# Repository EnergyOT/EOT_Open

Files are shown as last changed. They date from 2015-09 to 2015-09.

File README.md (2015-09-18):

### EOT Open

**Docs:** Documents with information

**Hardware:** PDF's of eagle schematic, board and BOM files for building your own EnergyOT

**Firmware:** An open firmware to be used with open platforms (thingspeak) that you can flash into your energyot meter instead of using the platform my.eot.pt. Beware that you if reprogram your device you will lose forever access to the platform my.eot.pt.

**Tools:** A set of helper tools for flashing and programming your EnergyOT.

**Website:** www.eot.pt

**Mail:** contact@energyot.pt

<br />This work is licensed under a <a rel="license" href="http://creativecommons.org/licenses/by-nc-sa/4.0/">Creative Commons Attribution-NonCommercial-ShareAlike 4.0 International License</a>.

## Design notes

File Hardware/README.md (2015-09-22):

## EOT Open Hardware

#### BOM

- **energyot_open_BOM.xlsx** - Bill of Materials

#### Schematic

- **energyot_open_schematic.pdf** - Schematic

#### Layout

- **energyot_open_top_layout.pdf** - PCB TOP
- **energyot_open_bottom_layout.pdf** - PCB BOTTOM
- **energyot_open_all_layout.pdf** - PCB COMPLETE

#### Programming Details

- **programming pads.png**
- **programming usb.png**

##TO PROGRAM

You will need an USB to serial converter (like FTDI or Prolific). Then there are two ways that you can program this hardware:

 - You can use the programming pads in the bottom side with pogopins or a custom made cable (check programming pads.png). 
 - You can close the solder jumpers in the bottom (J1, J2 and J3) and use the uUSB cable to program. Notice that after programming you should open the solder jumpers again check programming usb.png).
 
Notice that the usb to serial converter should be 3.3V and during the programming phase you will need to pull the GPIO0 pin to ground.

**Website:** www.eot.pt

**Mail:** contact@energyot.pt

<br />This work is licensed under a <a rel="license" href="http://creativecommons.org/licenses/by-nc-sa/4.0/">Creative Commons Attribution-NonCommercial-ShareAlike 4.0 International License</a>.

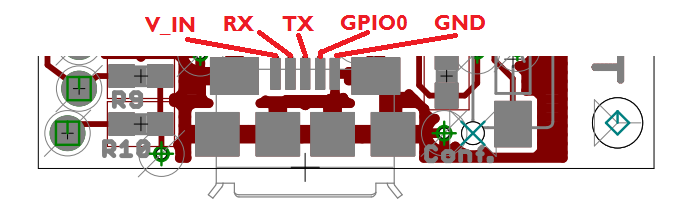
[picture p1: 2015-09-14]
Hardware/programming usb.PNG

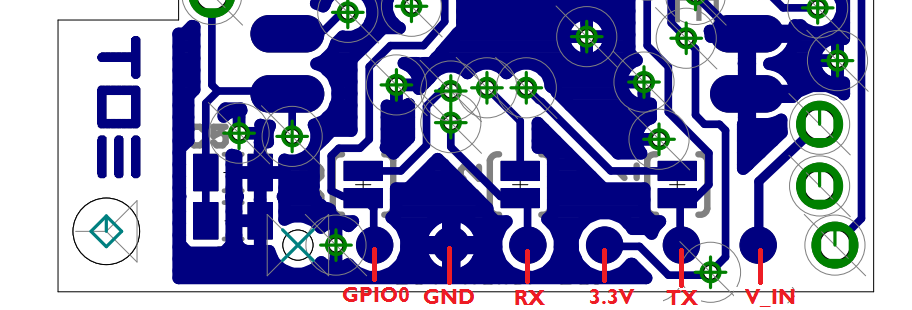
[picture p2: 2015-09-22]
Hardware/programming pads.PNG

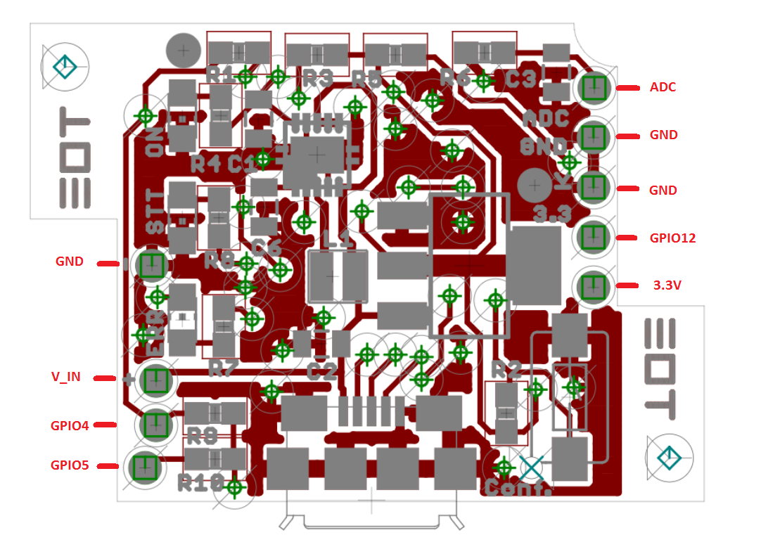
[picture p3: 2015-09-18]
Hardware/pinout.png

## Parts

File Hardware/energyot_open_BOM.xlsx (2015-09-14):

EnergyOT_OPEN V1.0 BOM
Part | Value | Device | Package (mils)
C1 | 22u, 16V | CAP0805 | 805
C2 | 10u, 16V | CAP0805 | 805
C3 | 1u, 16V | CAP0805 | 805
C4 | 10u, 16V | CAP0805 | 805
C5 | 0.1u, 16V | CAP0805 | 805
C6 | 1u, 16V | CAP0805 | 805
CONFIG. | SWITCH-MOMENTARY-2-SMD-1101NE | SWITCH-MOMENTARY-2-SMD-1101NE | TACTILE-SWITCH-1101NE
ESP12 | ESP12 | ESP12 | ESP12
L1 | 2.2uH | EPL2014-222MLC | EPL2014
ERR | RED | LEDCHIP-LED0805 | CHIP-LED0805
STT | BLUE | LEDCHIP-LED0805 | CHIP-LED0805
POW | GREEN | LEDCHIP-LED0805 | CHIP-LED0805
R1 | 4.7k | RESISTOR0603-RES | 0603-RES
R2 | 10k | RESISTOR0603-RES | 0603-RES
R3 | 10k | RESISTOR0603-RES | 0603-RES
R4 | 4.7k | RESISTOR0603-RES | 0603-RES
R5 | 10k | RESISTOR0603-RES | 0603-RES
R6 | 13k | RESISTOR0603-RES | 0603-RES
R7 | 4.7k | RESISTOR0603-RES | 0603-RES
R8 | 4.7k | RESISTOR0603-RES | 0603-RES
R9 | 4.7k | RESISTOR0603-RES | 0603-RES
R10 | 4.7k | RESISTOR0603-RES | 0603-RES
U_USB | 10118192-0001LF | 10118192-0001LF | 10118192-0001LF
IC1 | AP2114H-3.3TRG1 | AP2114H-3.3TRG1 | SOT-223
IC2 | TPS61201 | TPS61201 | S-PDSO-N10

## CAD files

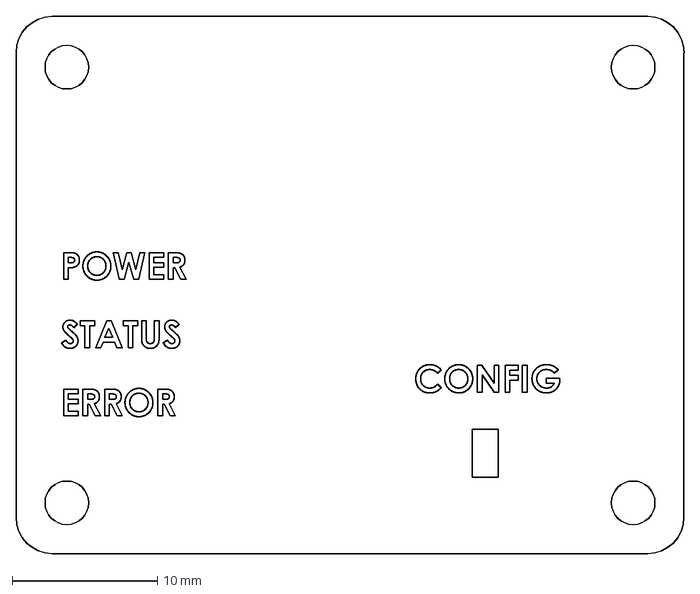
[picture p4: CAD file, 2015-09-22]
Enclosure/topo.DXF
46.0 x 37.0 mm

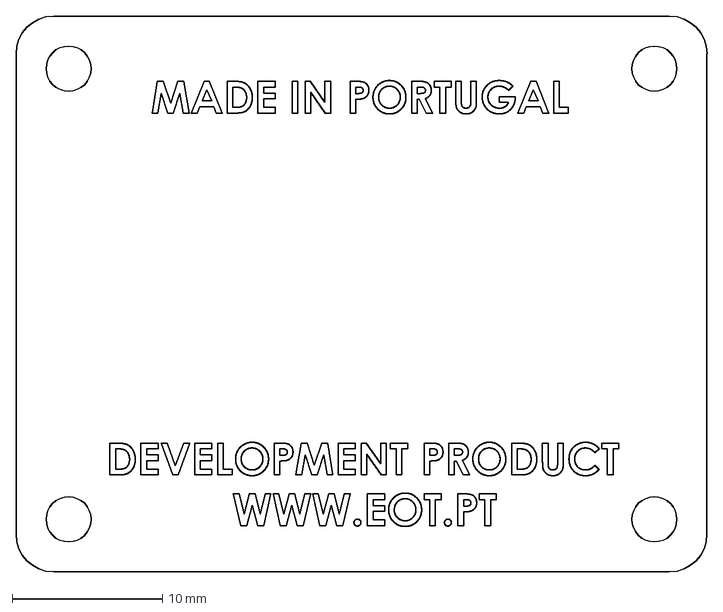
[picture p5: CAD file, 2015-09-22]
Enclosure/bottom.DXF
46.0 x 37.0 mm

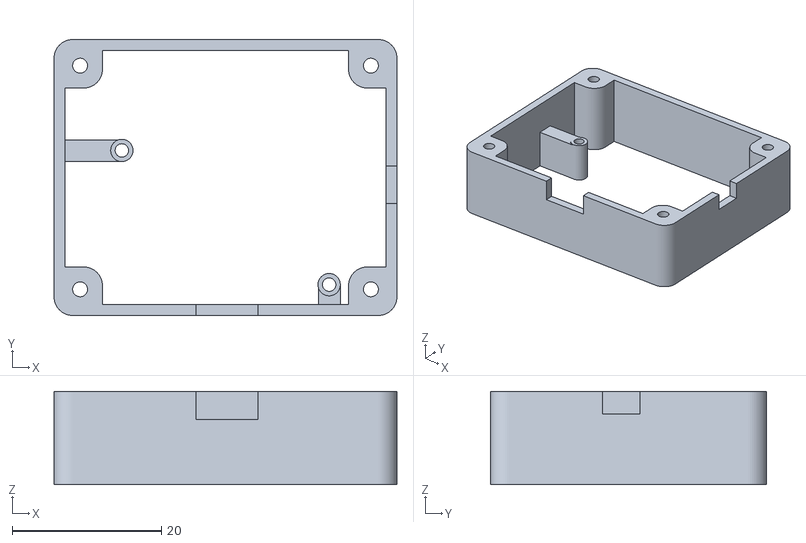
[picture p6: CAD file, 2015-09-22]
Enclosure/Middle 3D Print.STL
46.0 x 37.0 x 12.5

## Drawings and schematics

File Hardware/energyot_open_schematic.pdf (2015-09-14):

# 3.3V ERROR

A

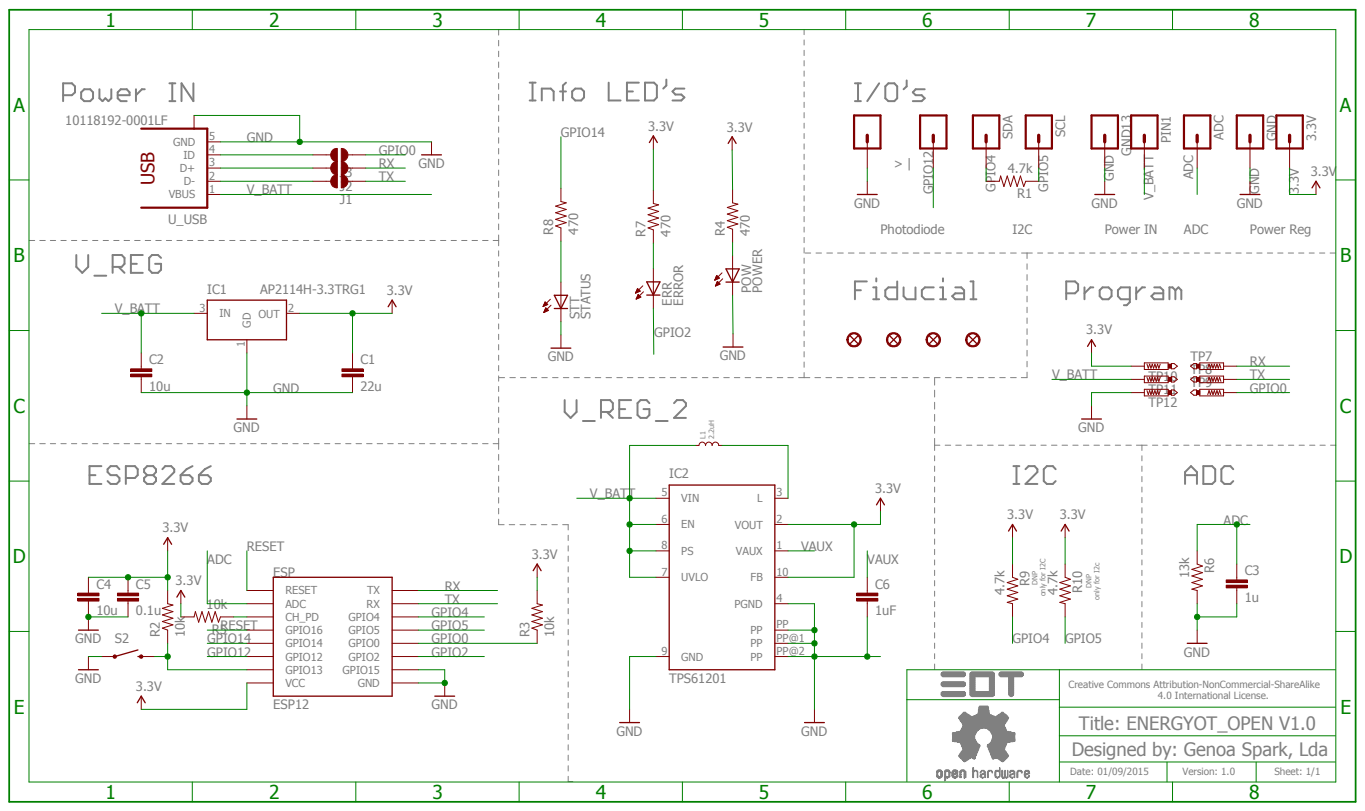
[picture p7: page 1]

Creative Commons Attribution-NonCommercial-ShareAlike

Title: ENERGYOT_OPEN V1.0
Designed by: Genoa Spark, Lda

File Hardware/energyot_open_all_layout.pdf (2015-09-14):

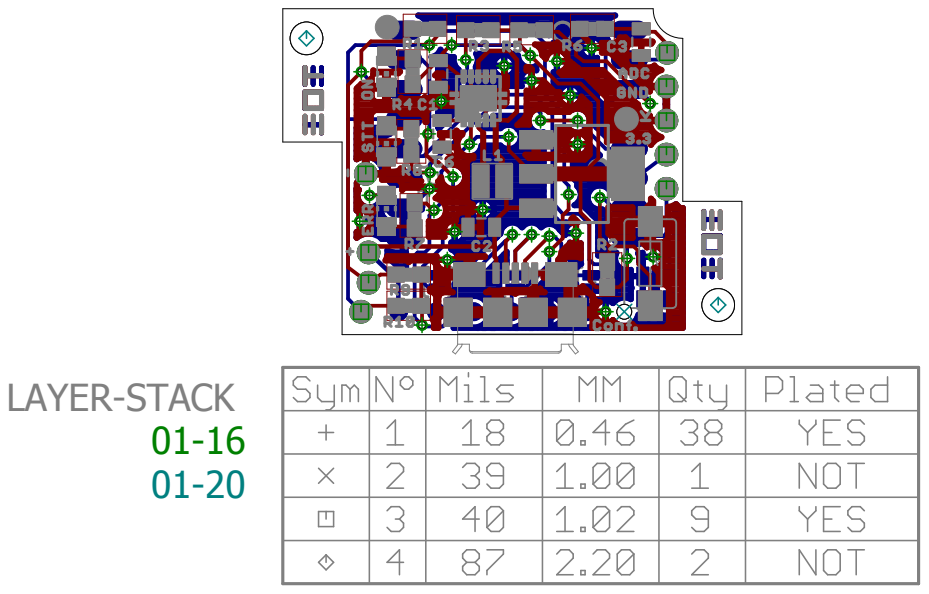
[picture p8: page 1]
ESP - 12; LAYER-STACK 01-16 01-20

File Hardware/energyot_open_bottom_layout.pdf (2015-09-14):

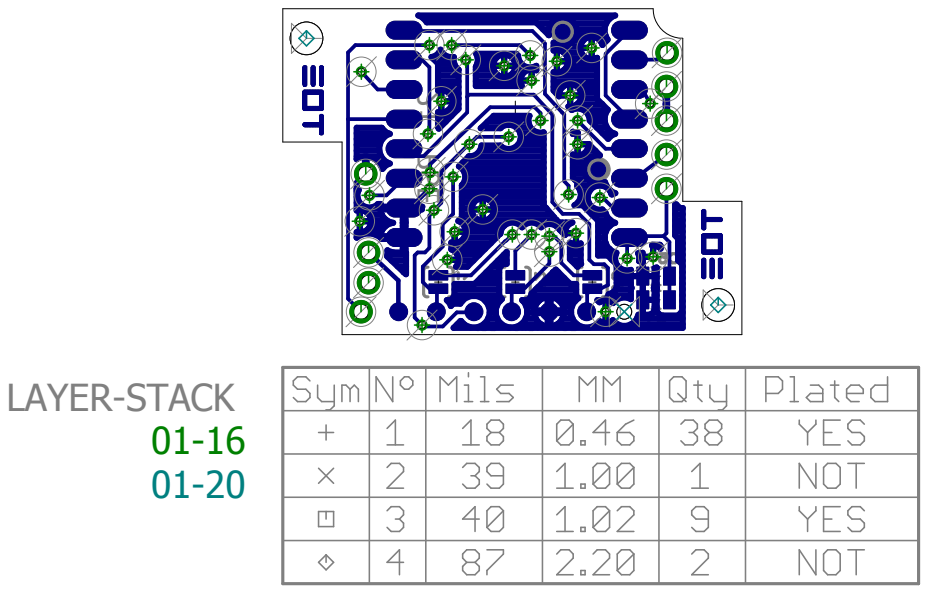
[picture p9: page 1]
ESP - 12; LAYER-STACK 01-16 01-20

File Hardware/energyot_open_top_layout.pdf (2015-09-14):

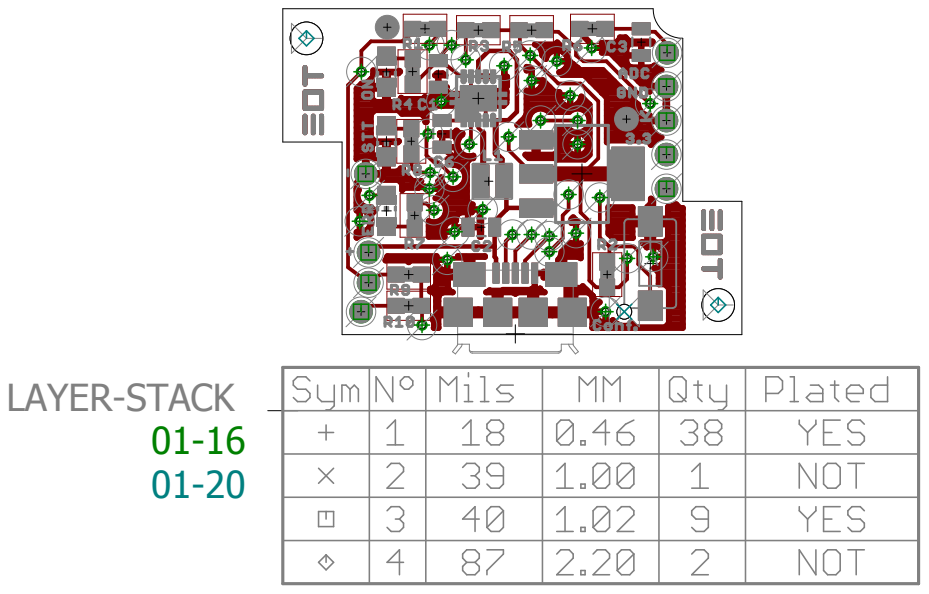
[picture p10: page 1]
LAYER-STACK 01-16 01-20

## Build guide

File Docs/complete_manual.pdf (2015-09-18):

## Version: Optic

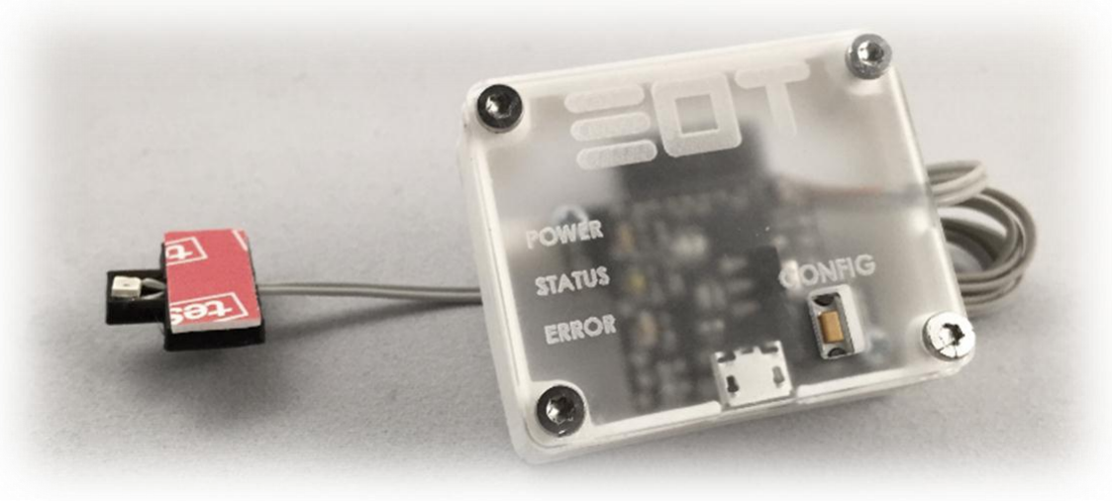
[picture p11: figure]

# COMPLETE MANUAL

September 2015 (English), version 1.0. EnergyOT Optic Developed and Manufactured by Genoa Spark, lda Made in Portugal

Specifications are subject to change without notice.
All product names are trademarks of their respective companies. http://www.eot.pt

# TABLE OF CONTENTS

# INTRODUCTION

The EnergyOT Optic version is a development device that measures the energy consumption of your home or business using an optical sensor that is glued to your energy meter, on top of the LED that indicates the Pulses/kWh. Once installed and configured this device reads, processes and sends the power consumption directly to your account in the cloud.

The EnergyOT uses the my.eot.pt platform to collect data and give you direct and real-time access to your energy consumption. To save on energy costs and contribute to a greener environment, you can use this information to take on energy guzzlers and standby power.

This manual describes the installation of the EnergyOT Optic version, as well as means of operation, configuration and troubleshoot.

# READ BEFORE USE

## MANUFACTURER'S DISCLAIMER STATEMENT

The information in this document is subject to change without notice and does not represent a commitment on the part of the vendor. No warranty or representation, either expressed or implied, is made with respect to the quality, accuracy or fitness for any particular purpose of this document. The manufacturer reserves the right to make changes to the content of this document and/or the products associated with it at any time without obligation to notify any person or organization of such changes. In no event will the manufacturer be liable for direct, indirect, special, incidental or consequential damages arising out of the use or inability to use this product or documentation, even if advised of the possibility of such damages.

This document contains materials protected by copyright. All rights are reserved. No part of this manual may be reproduced or transmitted in any form, by any means or for any purpose without expressed written consent of its authors. Product names appearing in this document are mentioned for identification purchases only. All trademarks, product names or brand names appearing in this document are registered property of their respective owners.

## WARNINGS

- Please observe the following safety precautions to avoid possible electric shocks, fire, or personal injury:
- Use the product only as specified as otherwise the safety of the product is not sufficient.
- Do not use the product in environments with explosive gas or vapors, nor in damp or wet environments.
- Do not use damaged power cords and cables. Check the power cords and cables for damaged insulation and exposed metal. Check the connection of the power cord.
- Do not use the product if it is damaged.
- Reparations should only be done by authorized technicians.
- Do not open the product. There is a potential for damaging the equipment.
- Do not cover the device with metallic materials or metallic tape. It will seriously reduce the Wi-Fi signal.

## MAINTENANCE

- Clean only the outside with a dry, clean cloth.
- Do not use abrasive agents, abrasive glues or solvents.
- Glue the device to the energy meter only with nonconductive tapes.
- Check the troubleshoot section or contact the support team before trying to manually fix a nonfunctioning device.

## TECHNICAL SPECIFICATIONS

- Dimensions: 37 mm (L) x 46 mm (W) x 18.5 mm (H)
- Wi-Fi 802.11 b/g/n 2.4 GHz
- Work temperature: -25°C to 50°C
- Storage temperature:-10°C to 60°C
- Relative humidity: 80%, 0°C to 40°C
- Work altitude: 0 to 2.000 meters
- Weight: 20g
- Enclosure Material: PLA

## WHAT'S IN THE BOX

Congratulations on being the owner of the EnergyOT Optic! Your box should include:

- EnergyOT Optic;
- Sensor with installation accessory.
- Documentation for installation and configuration.

# INSTALLATION INSTRUCTIONS

## DESCRIPTION

This section was developed to help you physically install the EnergyOT Optic in your energy meter. There is no need for an electrician since you won’t be touching any electric wires, just the energy meter itself. Follow the next set of quick instructions and you should be set.

## INSTALLATION

1. Using tape, center and attach the sensor on the Energy Meter led that indicates the Impulses by kWh. Check examples of the led location below;

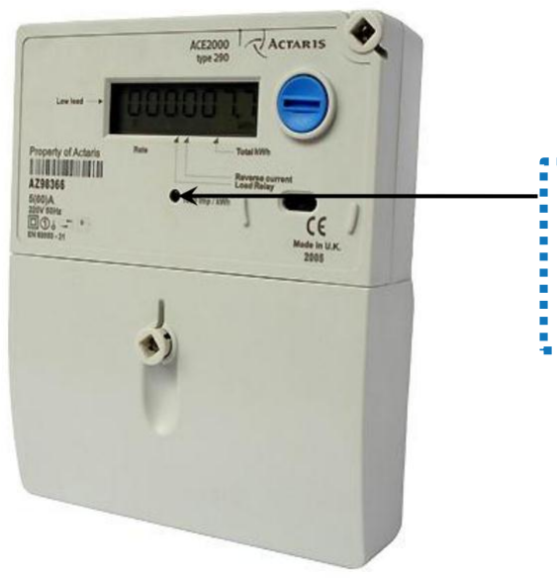
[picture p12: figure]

Location of the Imp/kWh
led where the sensor
should be placed.

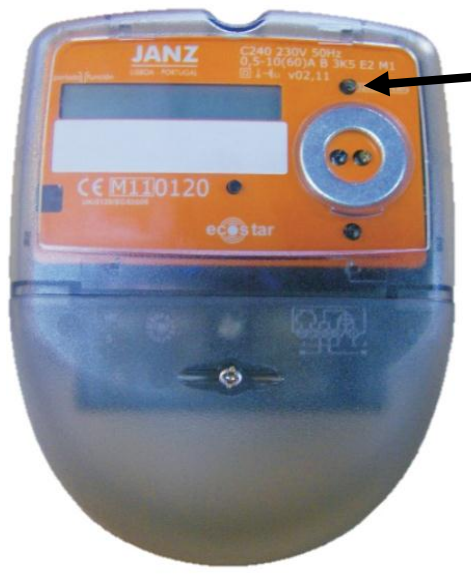
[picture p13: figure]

Location of the Imp/kWh
led where the sensor
should be placed.

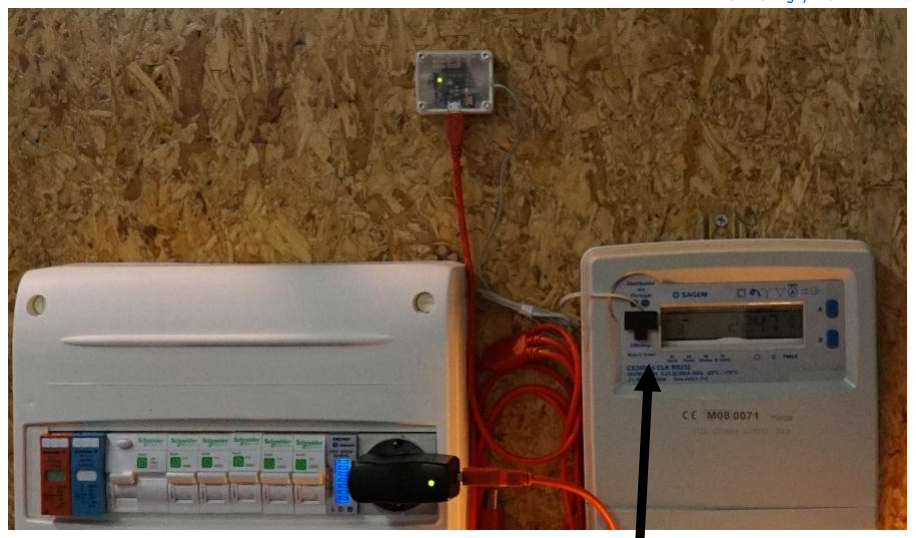
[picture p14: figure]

2. Place the EnergyOT monitor anywhere suitable for you but try to face it outside in order to access the configuration button, see the leds and maximize the wireless reach;
3. Connect the mini USB power cable supplied to the EnergyOT monitor and the green Led should light up indicating that is powered;
4. Also the blue led should be on and the red led should be blinking indicating that the device is new and not yet configured to a wireless network. To configure it check the operation section of this manual;
5. If you are experiencing any problems with the installation check the troubleshoot section of this manual or contact the support team.

If you are finding it difficult to glue the EnergyOT to your Energy Meter you may add more double sided tape or other type of tape to secure the sensor to your Energy Meter.

Sensor applied in the energy Meter

# OPERATION INSTRUCTIONS

## DESCRIPTION

This guide was developed to help you configure your EnergyOT Optic. This guide assumes that you already have the EnergyOT Optic installed in place. If so follow the next set of quick instructions otherwise check the installation section in this manual first.

## FRONT PANEL

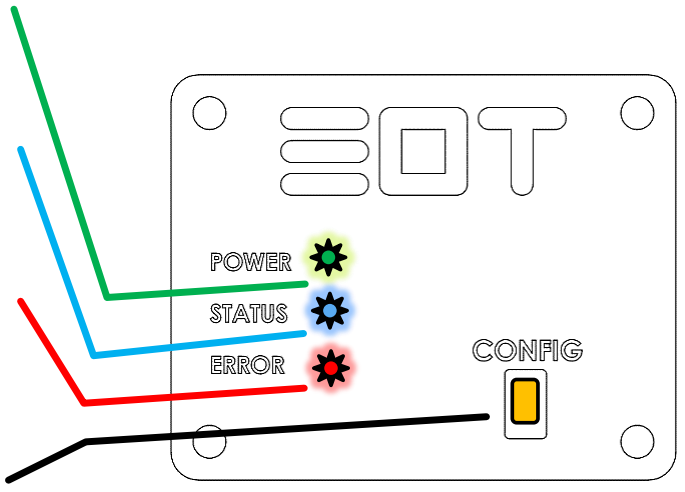
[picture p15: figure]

## CONFIGURING YOUR DEVICE TO YOUR

## NETWORK

1. You must register in the my.eot.pt platform before starting the device configuration.
2. Plug the micro USB to the EnergyOT device in order to power it.
3. You have 5 seconds from the moment you power the EnergyOT to press the configuration button.
4. All LEDs will light up (green, blue and red) indicating that the device is now in configuration mode (If by any chance you have not been able to press the Config. button within the 5 second limit switch it off, turn it on and try again) .
5. Download the configuration tool that best suit the platform that will use (Windows, Mac, Linux or Android) in www.eot.pt/en/downloads.html
6. Follow the instructions of the configuration tools. Briefly these applications will point you to:

Power Led – Indicates if the device is powered.

Status Led – Blinks accordingly with the energy consumption.

Error Led – Indicates the existence of errors.

Configuration Button – To configure your EnergyOT.

a. Login in the application with the email and password of your account in the my.eot.pt platform and choose to activate a new EnergyOT;

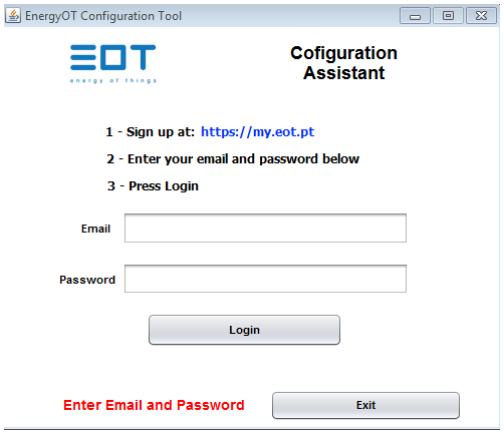
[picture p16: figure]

b. Enter the SSID and password of your wireless network.

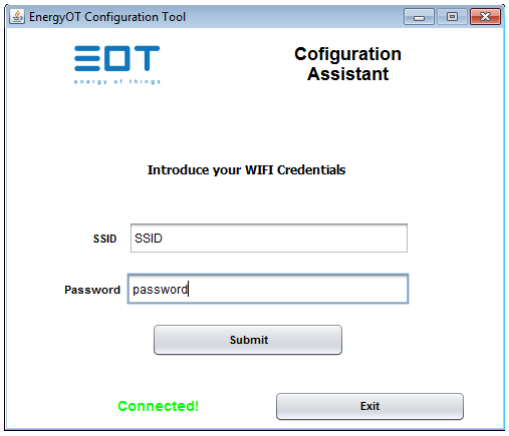
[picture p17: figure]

c. After you have entered all the parameters change your wireless network and connect to the network generated by the EnergyOT (the SSID of the network is EnergyOT xx-xx-xx-xx).
d. Make sure that at this stage your computer is connected to the EnergyOT (EnergyOT xx-xx-xx-xx), and click "Configure EnergyOT".

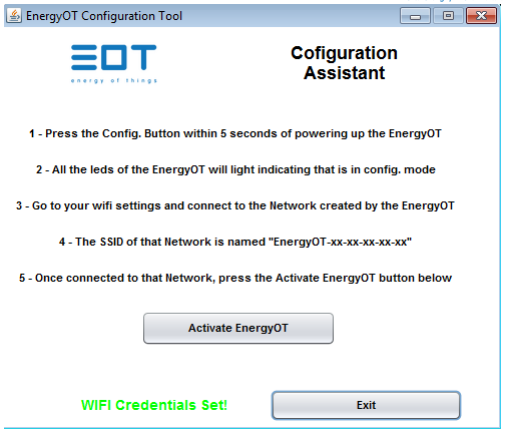
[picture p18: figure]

7. The EnergyOT Monitor is now configured! Congratulations! Now you can check your data online.
8. If you are experiencing any problems with the configuration check the troubleshoot section in this manual or contact the support team.

If you want to change or made a mistake entering your network SSID or Password, you need to go back to step 1 again.

# TROUBLESHOOT

## DESCRIPTION

When operating the EnergyOT Óptic device you may run into issues. This is a handy guide to some simple-to-fix problems. Also, if your device has been stolen, contact us so that we can disable the equipment.

## SUPPORT

If you have any questions regarding the EnergyOT Optic that are not contemplated in this troubleshoot section please send an email to our support team: contact@energyot.pt.

Problem | Solution
The device doesn’t turn on (green led doesn’t light up). | • Try to replace the micro USB power supply unit. • Have any components been damaged? Visually inspect both sides of the device. • Try to press the configuration button shortly after powering it up to see if the other two led’s light up (If so, the device works but the green led is broken).
The device does not send data - The blue led is on and the red led is blinking. | • The EnergyOT Optic is not configured to your Network, follow the instruction in the Operations section to configure it.
The device does not send data – The blue and red led’s are blinking synchronously. | • The device failed to connect with the platform, try to re-configure it and contact the support team.
The device enters in configuration mode (all leds light up) but never leaves this state after I send my network credentials. | • Confirm that you are connected to the access point generated by the EnergyOT Optic (The SSID should be EnergyOT-xx-xx-xx-xx-xx”) when you send your credentials to the EnergyOT. • Try to configure it again with configuration application available in www.eot.pt/downloads.html.
The device does not send data - The red led is always on | • No network response: Check if the Network where the EnergyOT Optic is linked is connected to the internet.

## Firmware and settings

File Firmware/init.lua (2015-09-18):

gpio.mode(4,gpio.OUTPUT) -- RED LED - Set as OUTPUT
gpio.mode(5,gpio.OUTPUT) -- White/blue LED - Set as OUTPUT
gpio.mode(7,gpio.INPUT) -- Push button input pin - Set as INTPUT

gpio.write(4, gpio.HIGH)  -- Turn off Red LED, Active LOW
gpio.write(5, gpio.LOW)   -- Turn off White/blue LED

--CONFIG 
api_key = "xxxxxxxxx" --Enter Your thingspeak api KEY Here

--Wifi Details, your wifi router or AP credentials 
ssid= "mySSID" -- Enter Your WIFI SSID Here
pswrd= "mywifiPWD" -- Enter Your WIFI Password Here

--Meter Details 
--Ex. 1000 imp/kHw => imp=1000 and kWh=1
--Ex. 3200 imp/kHw => imp=3200 and kWh=1
--Ex. 1000 imp/kHw => imp=1000 and kWh=1
imp=1000
kWh=1

--Vars
tE = 0 
last = 0
last_sent = 0
count= 0

function test_wifi()
    print("test wifi ") 
    if (wifi.sta.status() == 5) then     
            gpio.write(4, gpio.HIGH) 
    else
            gpio.write(4, gpio.LOW) 
    end
end

function launch()
  test_wifi()
  gpio.mode(6,gpio.INT,gpio.PULLUP) 
  gpio.trig(6, "down",counter) --set a trigger on the falling edge.
end

function send_counter(count,tempo)
    test_wifi()
    power=(3600000*imp/tempo)  
    power=power*count*kWh
    conn=net.createConnection(net.TCP, 0)
    conn:on("receive", function(conn, payload) print("Pd: "..payload) conn:close() end)         
    conn:connect(80,"184.106.153.149") -- thingspeak IP
    conn:send("GET /update?key="..api_key.."&field1="..power.." \r\n Host:api.thingspeak.com\r\n"
    .."Connection: close\r\nAccept: */*\r\n\r\n")
    conn:on("sent",function(c) conn:close() end)
end

function counter(level)
    if level==1 then  -- "debounce" only falling edge is to be considered.
        return 
    end  
    if  ((tmr.now()<tE) or (tmr.now()-tE > 10000)) then        
        tE=tmr.now() 
        count=count+1
        tempo=(tE-last) 
        if (last == 0) then
            last=tmr.now()
            count=0
        end

        gpio.write(5, gpio.HIGH) --blink to indicate the pulse
        tmr.delay(1000)
        gpio.write(5, gpio.LOW) 

        if (((tmr.now()-last_sent<0) or  (tmr.now()-last_sent) >= 15500000) and count>0) then   
            send_counter(count,tempo)
            last=tE 
            last_sent=tmr.now()
            count=0
        end 
    end
end

--CODE

print("set wifi ") 
wifi.setmode(wifi.STATION) -- Set Wifi mode as Station, to connect the the rou
wifi.sta.config(ssid,pswrd)
wifi=nil
ssid=nil

--Start listening for pulses
print("set trigger ")
launch() 


       
